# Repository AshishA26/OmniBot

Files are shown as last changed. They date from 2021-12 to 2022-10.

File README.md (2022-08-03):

# OmniBot
A remote-controlled robot that has the ability to move in more directions than usually possible using unique mecanum wheels. 
Controlled using a custom-designed Joystick and nRF24L01 module.
Programmed in `Platform IO`, models created in `Solidworks`, schematics created in `KiCad`.

Some very short demos below (click on each one to visit the full video):
Link to youtube video (https://www.youtube.com/watch?v=i19Mjydu3dY)
Link to youtube video (https://www.youtube.com/watch?v=ooEIl0JvQ7g)

## Notes
- Upload the OmniBot-Joystick.ino in the `src/OmniBot-Joystick` folder to the joystick
- The entire `Platform IO` project is to be uploaded to the OmniBot
- The OmniBot-Joystick is a slightly modified version of my [RC-Joystick](https://github.com/AshishA26/RC-Joystick).

## Schematics
Schematic for the OmniBot:
OmniBot Schematic

Schematic for the OmniBot Joystick:
OmniBot Joystick Schematic

## Images

The OmniBot and Joystick side by side:
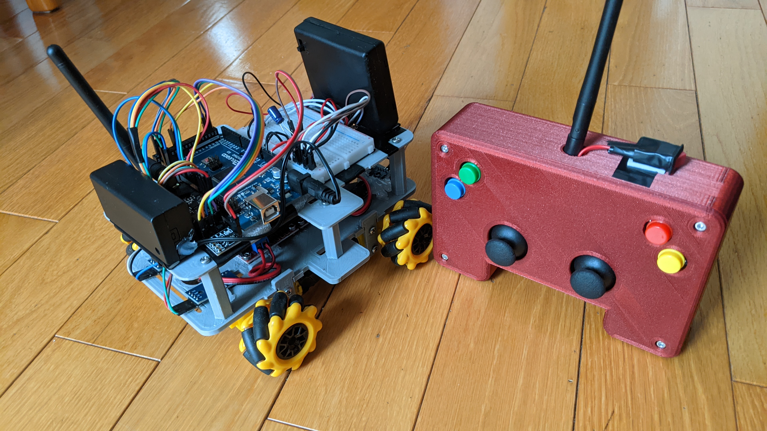
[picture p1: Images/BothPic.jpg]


<!--The OmniBot:
<img src="./Images/OmniBotPic1.jpg" width="" height="200">
<img src="./Images/OmniBotPic2.jpg" width="" height="200">
-->

Inside the joystick:
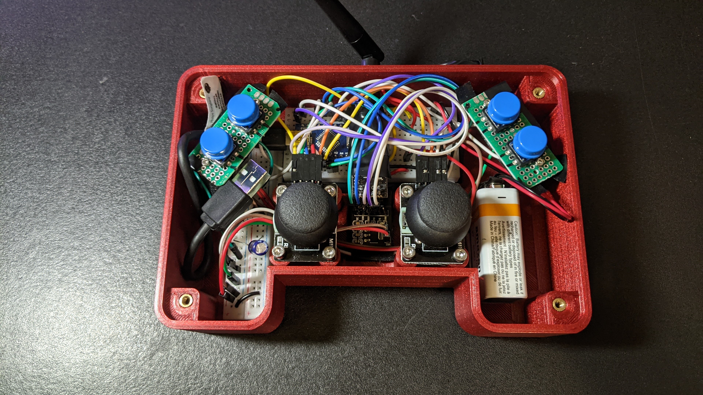
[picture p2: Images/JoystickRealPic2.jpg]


Rendered pictures of the 3D model I created using parts from [GrabCAD](https://grabcad.com/library) combined with my own models designed for 3D printing. Made in real-world scale and was designed using `Solidworks`:

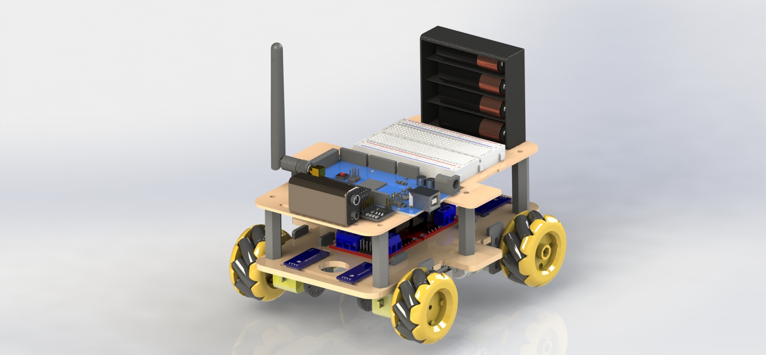
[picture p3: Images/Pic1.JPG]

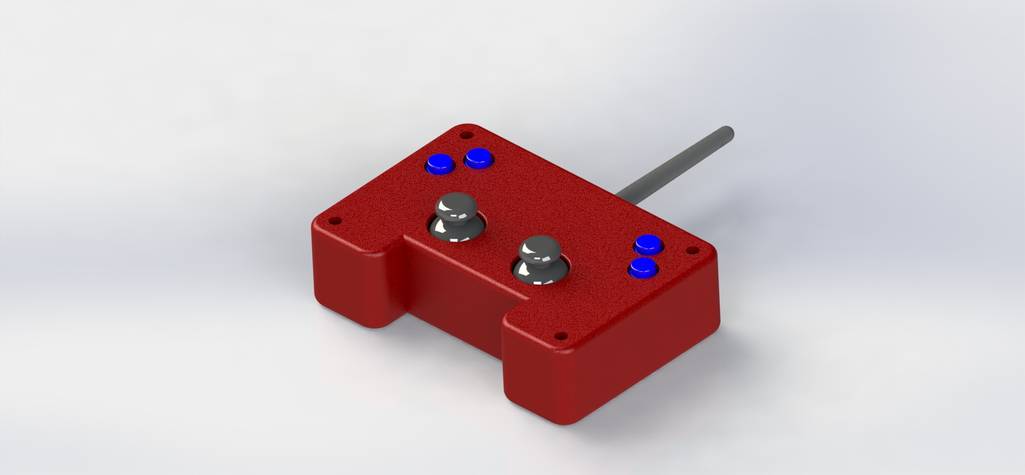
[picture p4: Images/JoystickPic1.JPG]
JoystickPic1


For more images, please see the [images folder](https://github.com/AshishA26/OmniBot/tree/master/Images) of this repo.

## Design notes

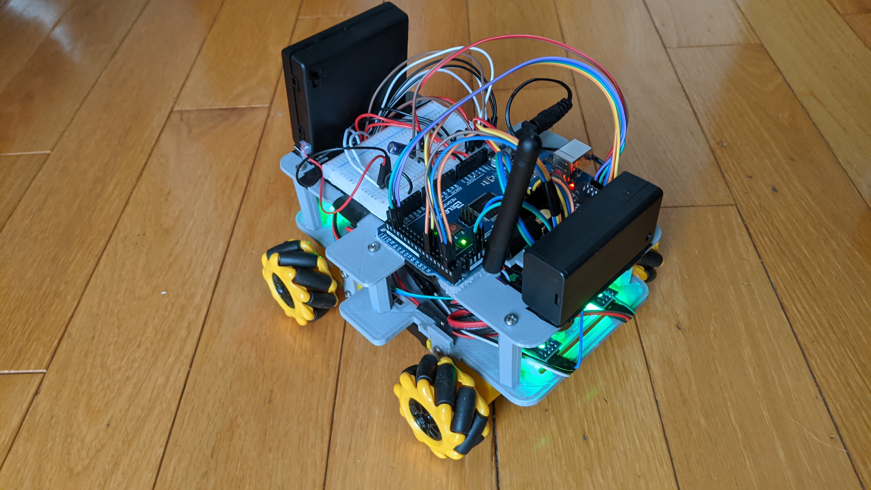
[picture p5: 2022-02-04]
Images/OmniBotPic1.jpg

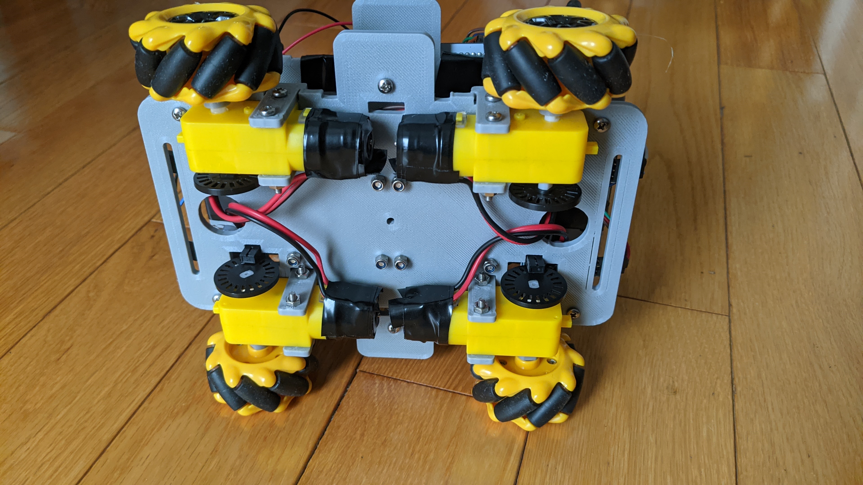
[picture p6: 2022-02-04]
Images/OmniBotPic2.jpg

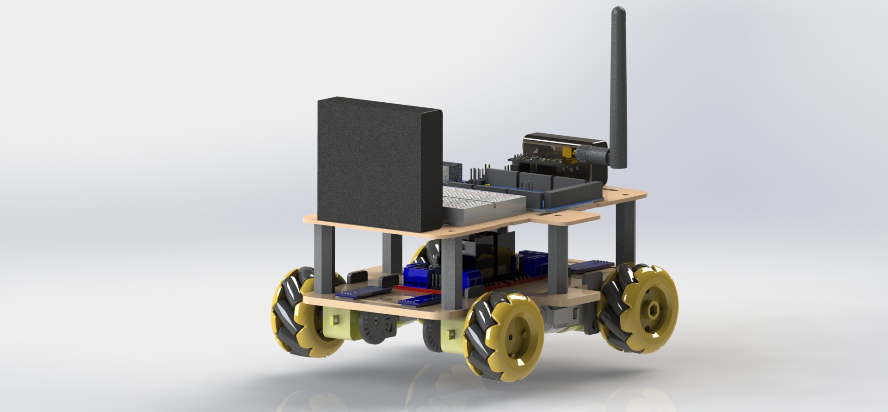
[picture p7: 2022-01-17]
Images/Pic2.JPG

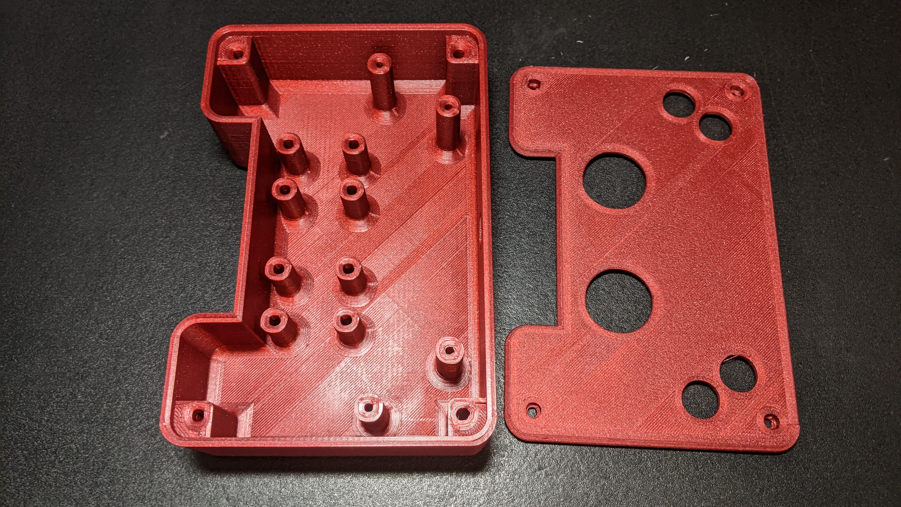
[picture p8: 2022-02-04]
Images/JoystickRealPic3.jpg

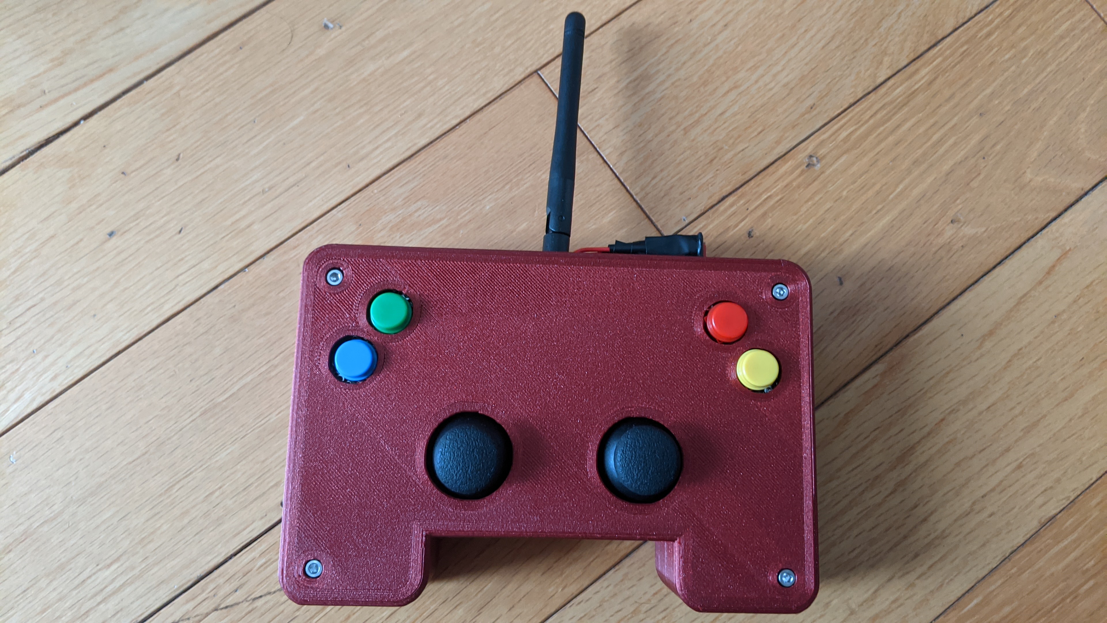
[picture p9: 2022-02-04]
Images/JoystickRealPic1.jpg

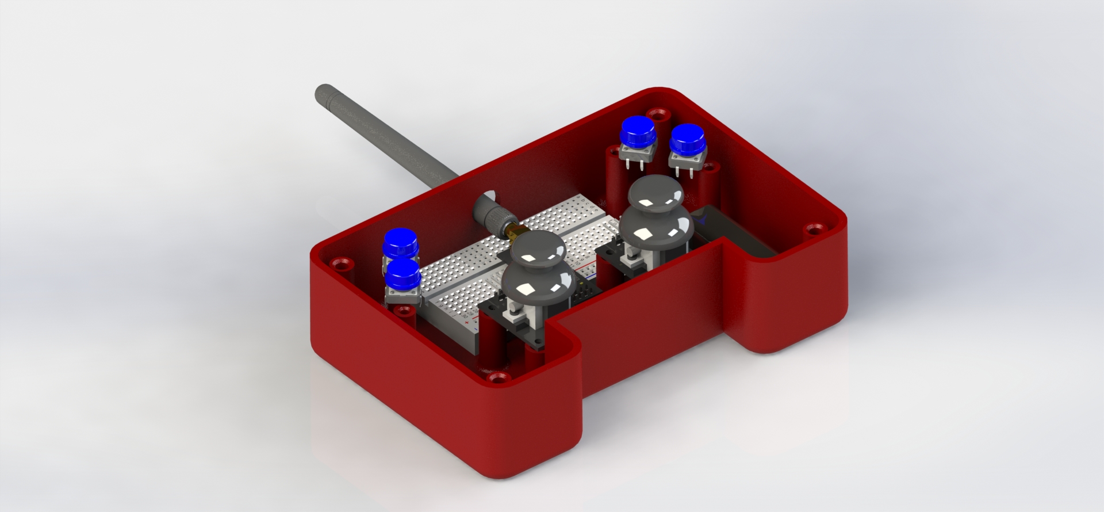
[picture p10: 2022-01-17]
Images/JoystickPic2.JPG

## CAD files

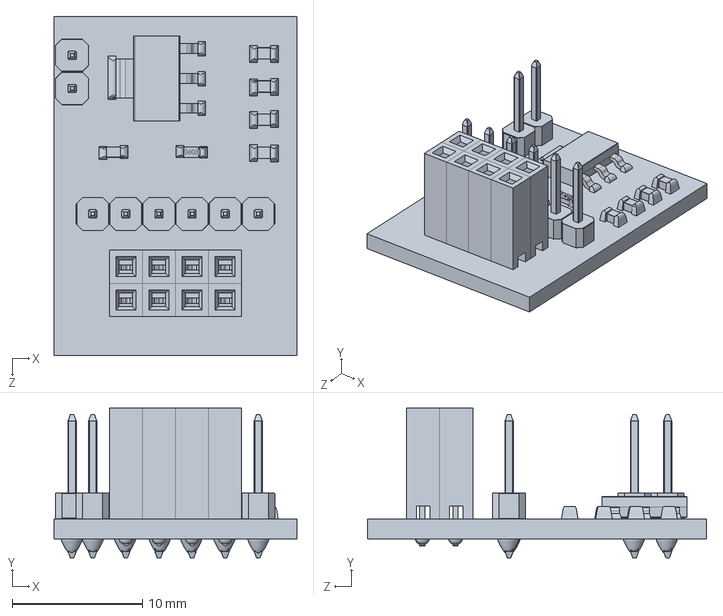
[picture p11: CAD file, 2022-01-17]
Models/OmniBotAssembly/NRFL24L01_Power_Board_asm.SLDPRT
18.6 x 11.5 x 26.0 mm

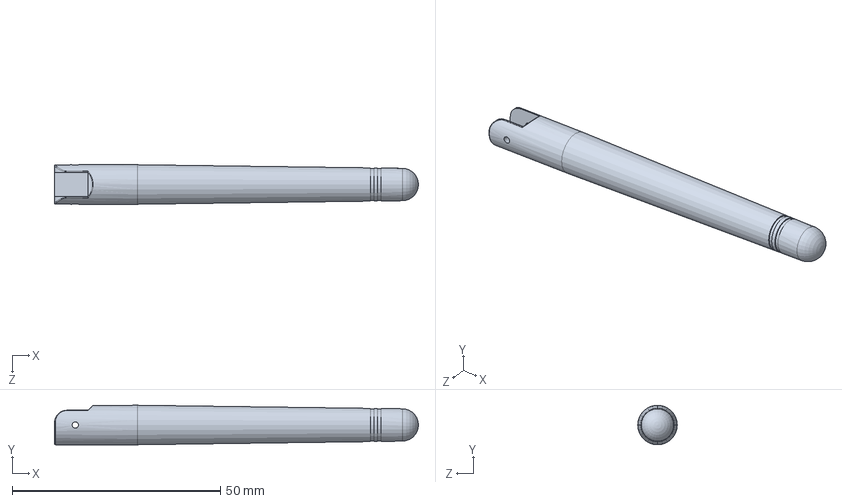
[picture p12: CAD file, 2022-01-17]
Models/OmniBotAssembly/Antenna.SLDPRT
87.5 x 9.50 x 9.50 mm

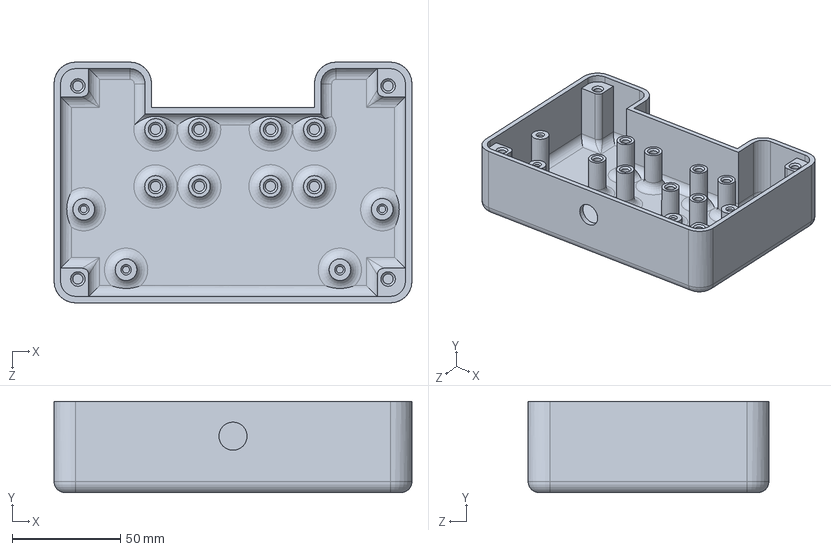
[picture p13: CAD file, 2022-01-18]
Models/OmniBotJoystickAssembly/Joystick.SLDPRT
165.0 x 42.0 x 111.0 mm

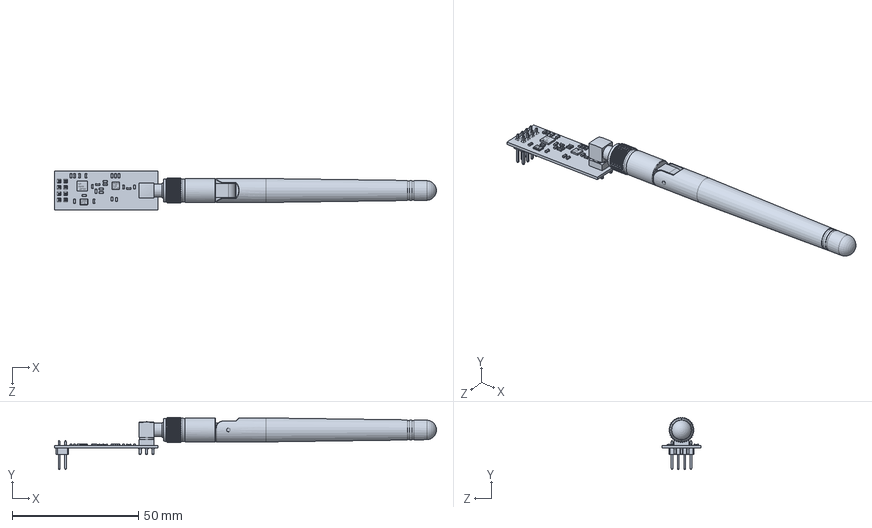
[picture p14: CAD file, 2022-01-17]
Models/OmniBotAssembly/NRF24L01L+Antenna.SLDPRT
151.4 x 20.7 x 15.5 mm

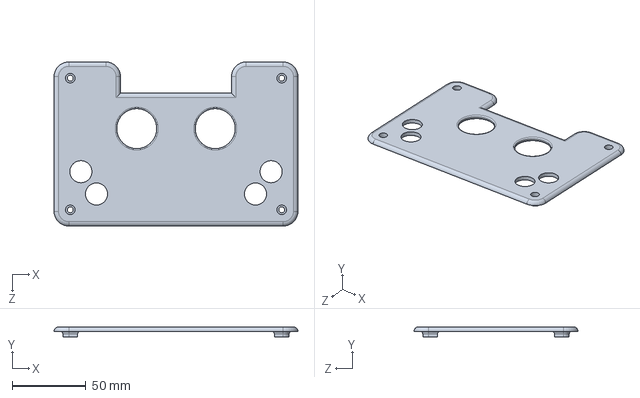
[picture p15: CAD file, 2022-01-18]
Models/OmniBotJoystickAssembly/Joystick_Lid.SLDPRT
165.0 x 6.90 x 111.0 mm

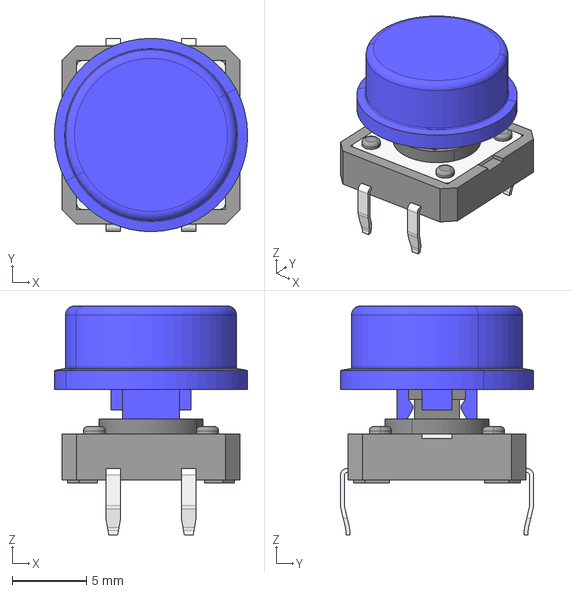
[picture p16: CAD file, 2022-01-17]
Models/OmniBotJoystickAssembly/Button microswitch_P-B1729+B17172_blue.stp
13.0 x 13.0 x 15.4 mm

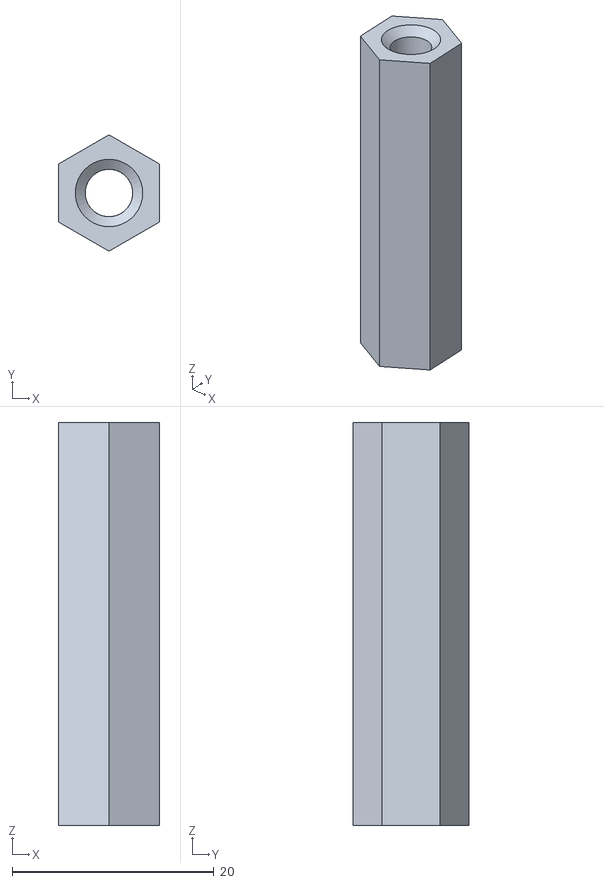
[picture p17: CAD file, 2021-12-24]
Models/STL/StandOffs.STL
10.0 x 11.5 x 40.0

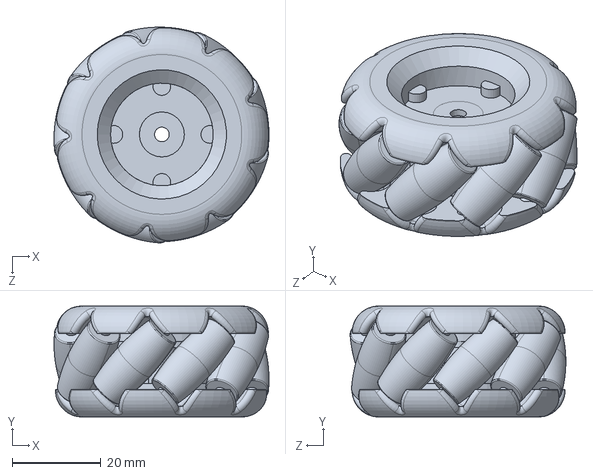
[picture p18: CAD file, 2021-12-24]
Models/OmniBotAssembly/Mecanum Left.SLDPRT
48.4 x 25.0 x 48.6 mm

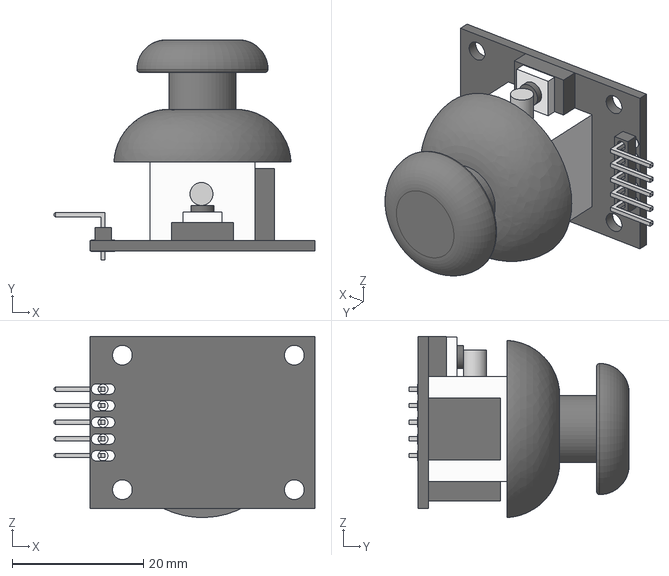
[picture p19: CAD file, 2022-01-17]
Models/OmniBotJoystickAssembly/joy_stick_2a.step
39.8 x 33.6 x 27.6 mm

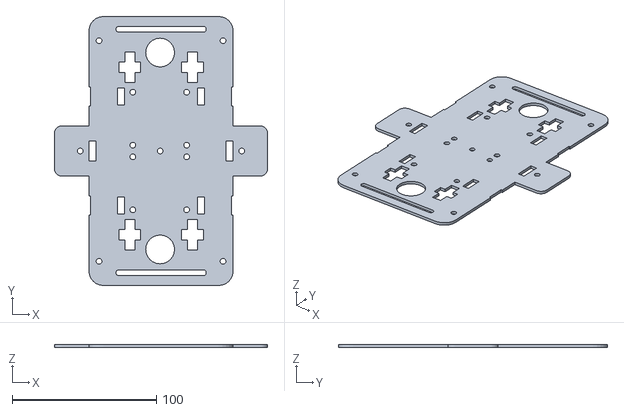
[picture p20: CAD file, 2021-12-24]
Models/STL/ChassisTop.STL
148.0 x 186.7 x 2.00

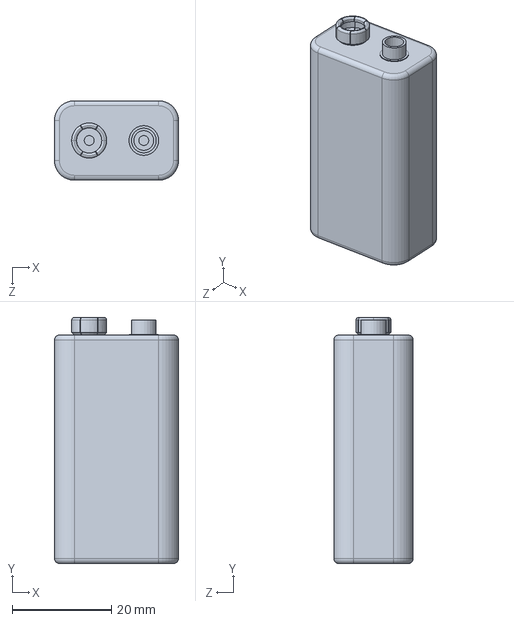
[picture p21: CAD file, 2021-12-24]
Models/OmniBotAssembly/9V-2.SLDPRT
25.0 x 49.5 x 16.0 mm

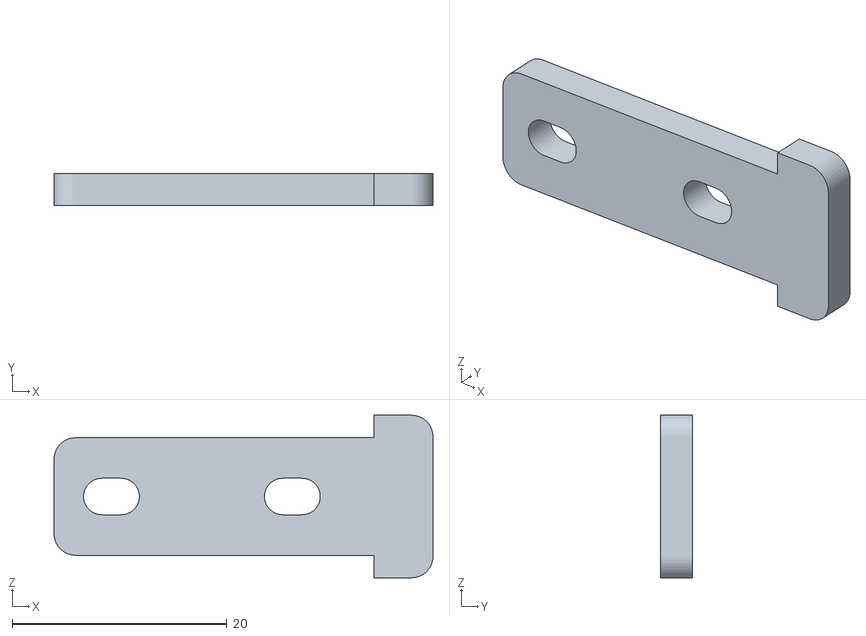
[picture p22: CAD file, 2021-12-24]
Models/STL/MotorStands.STL
35.3 x 3.00 x 15.2

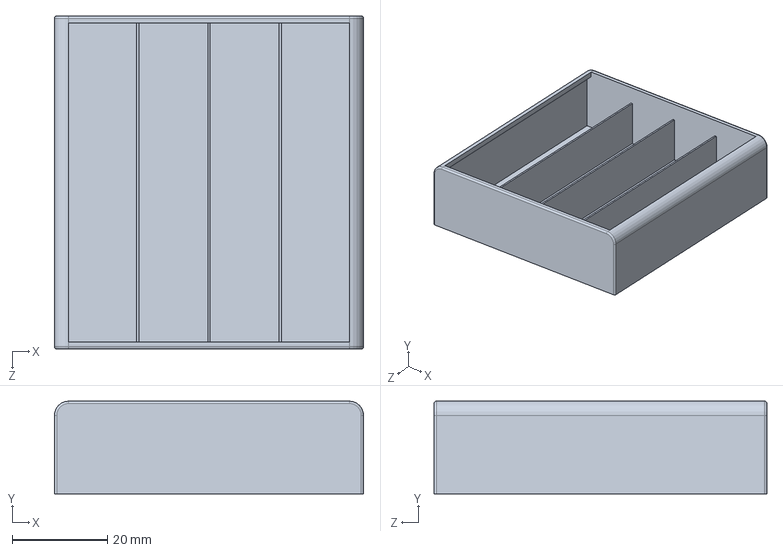
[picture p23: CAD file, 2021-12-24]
Models/OmniBotAssembly/Battery Holder.SLDPRT
65.0 x 19.5 x 70.0 mm

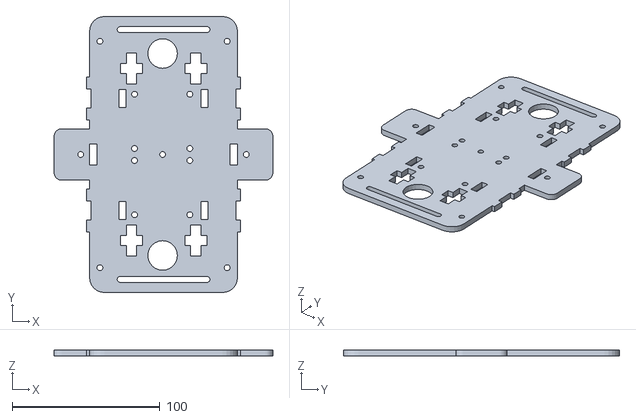
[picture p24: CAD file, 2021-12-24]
Models/STL/ChassisBottom.STL
148.0 x 186.7 x 4.00

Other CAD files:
Models/STL/Joystick.STL
Models/STL/Joystick_Lid.STL
Models/OmniBotJoystickAssembly/joy_stick_a2.iges
Models/OmniBotAssembly/AA Duracell Body.SLDPRT
Models/OmniBotAssembly/Arduino Mega 2560.SLDPRT
Models/OmniBotAssembly/ChassisBottom.SLDPRT
Models/OmniBotAssembly/ChassisTop.SLDPRT
Models/OmniBotAssembly/Lm393 Motor Speed Measuring Sensor Module.SLDPRT
Models/OmniBotAssembly/Motor Stand.SLDPRT
Models/OmniBotAssembly/Motor.SLDDRW
Models/OmniBotAssembly/Motor.SLDPRT
Models/OmniBotAssembly/StandOffs.SLDPRT
Models/OmniBotAssembly/encoder20p.SLDPRT

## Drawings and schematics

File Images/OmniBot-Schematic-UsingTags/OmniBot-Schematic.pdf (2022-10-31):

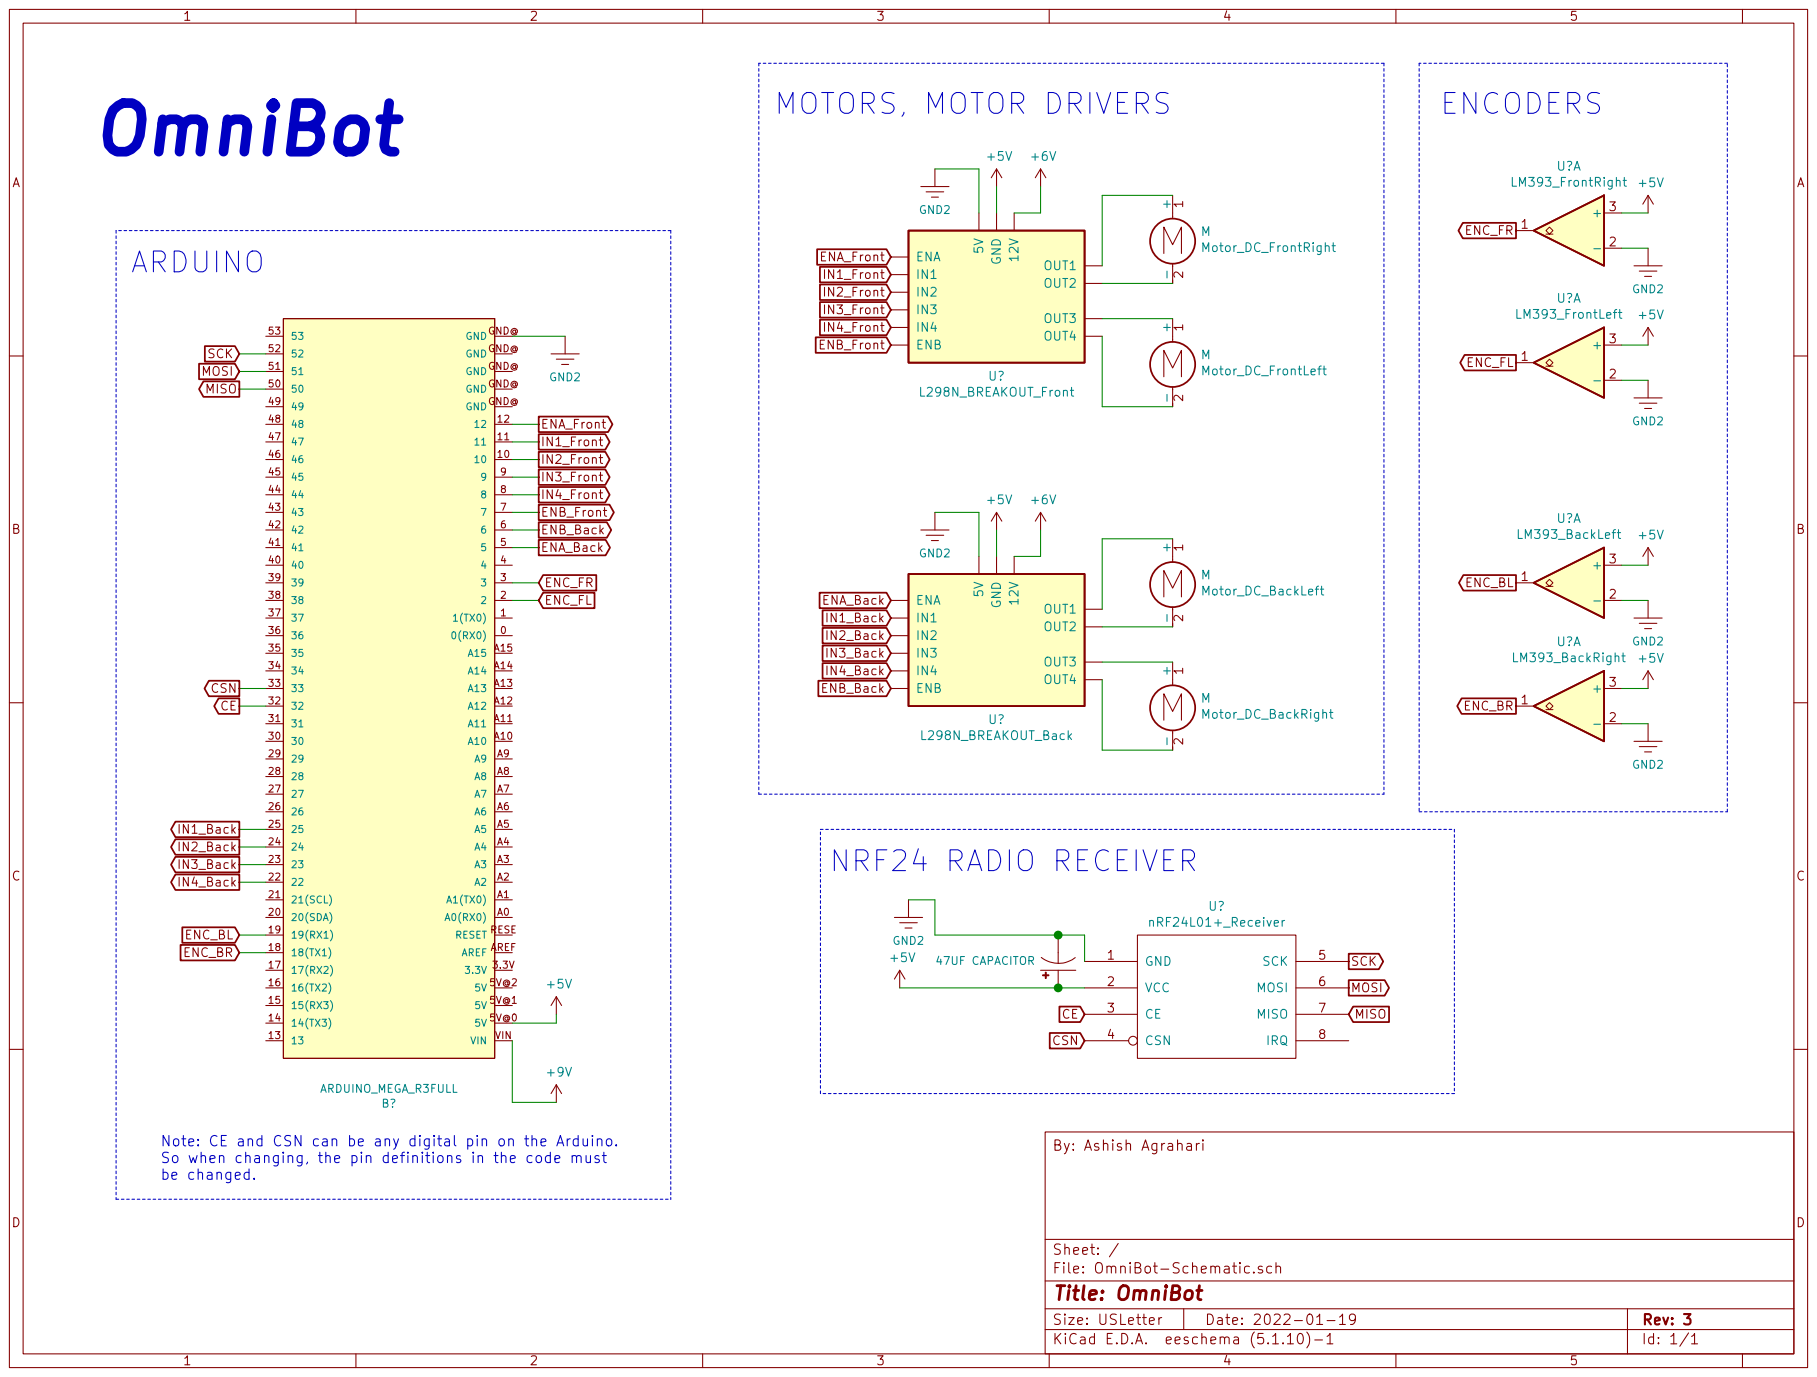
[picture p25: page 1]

Id: 1/1 Title: OmniBot File: OmniBot-Schematic.sch Sheet: / By: Ashish Agrahari 47UF CAPACITOR

Note: CE and CSN can be any digital pin on the Arduino.
So when changing, the pin definitions in the code must
be changed.

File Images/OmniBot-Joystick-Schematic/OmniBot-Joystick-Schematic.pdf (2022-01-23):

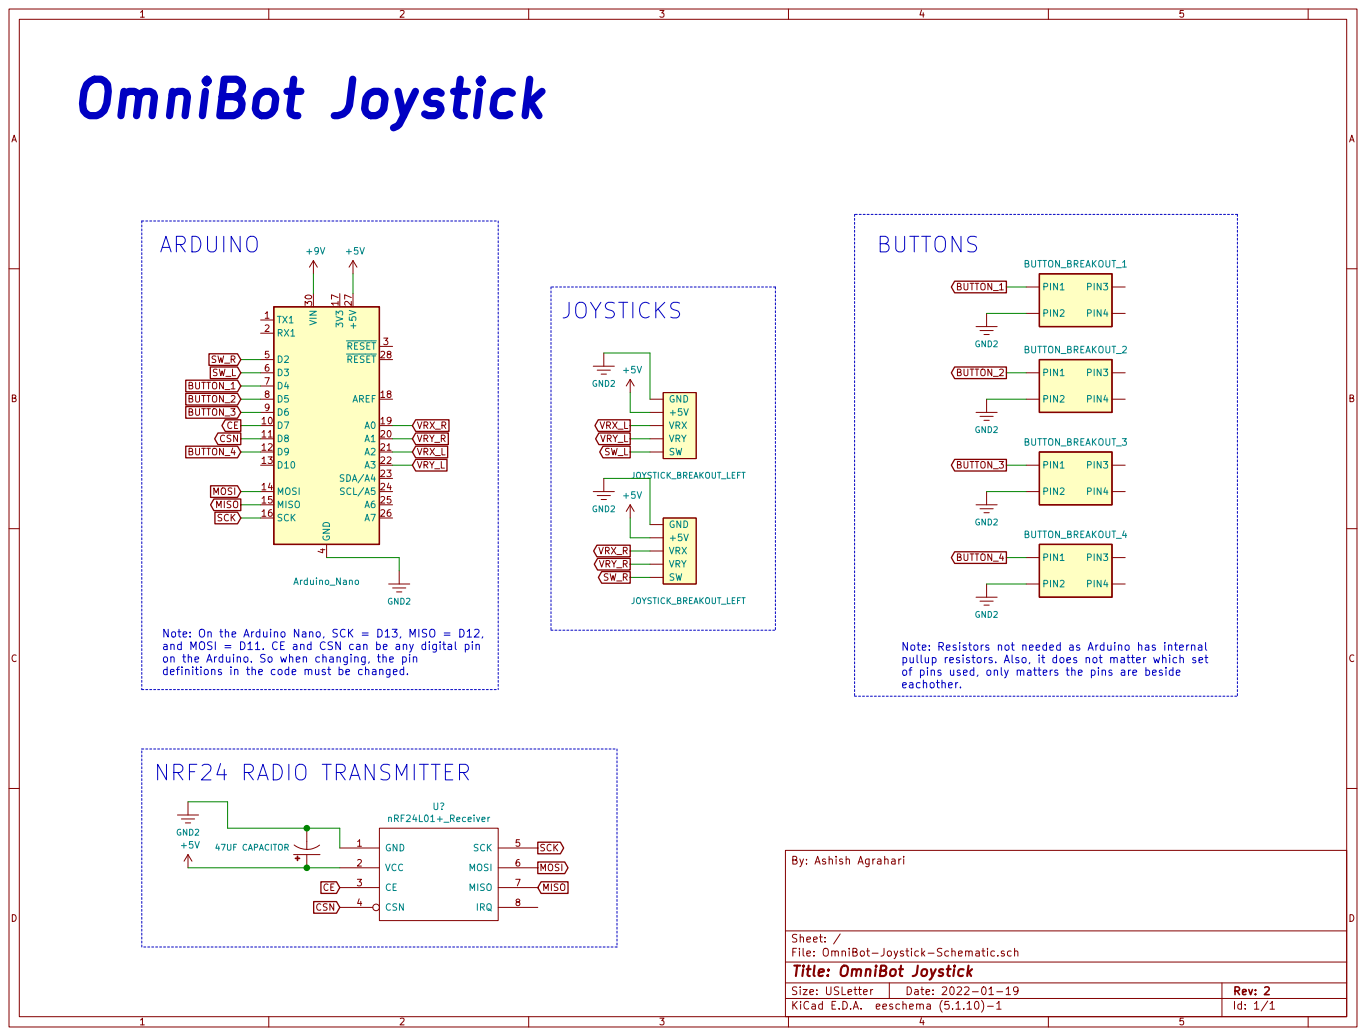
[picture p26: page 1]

of pins used, only matters the pins are beside eachother. ARDUINO

File: OmniBot-Joystick-Schematic.sch Sheet: / By: Ashish Agrahari +5V GND

Note: On the Arduino Nano, SCK = D13, MISO = D12,
and MOSI = D11. CE and CSN can be any digital pin
on the Arduino. So when changing, the pin
definitions in the code must be changed.

Id: 1/1 Title: OmniBot Joystick

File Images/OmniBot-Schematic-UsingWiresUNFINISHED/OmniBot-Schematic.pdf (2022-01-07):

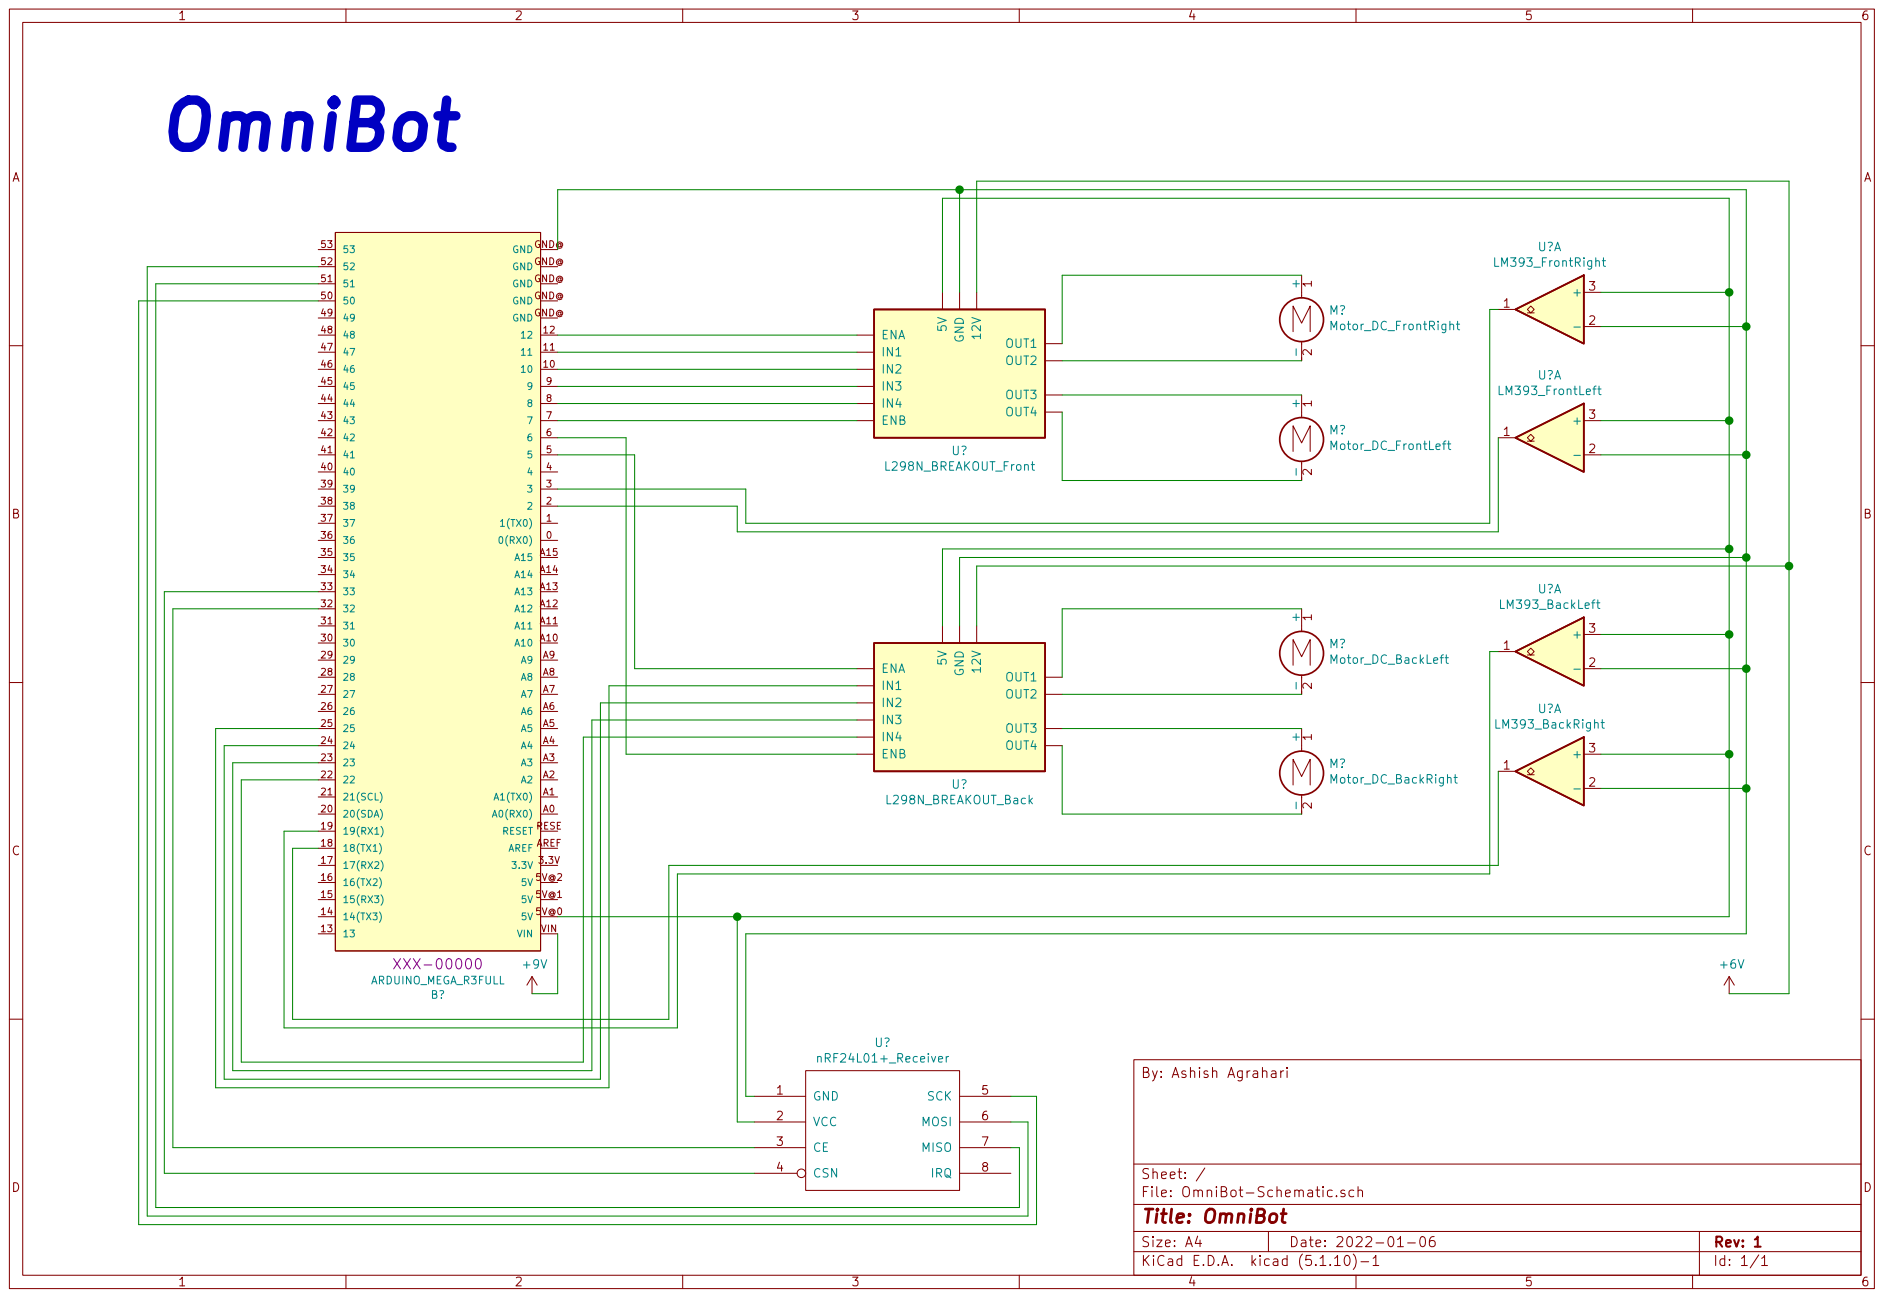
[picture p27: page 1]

51 51 GNDGND@
50 50 GNDGND@

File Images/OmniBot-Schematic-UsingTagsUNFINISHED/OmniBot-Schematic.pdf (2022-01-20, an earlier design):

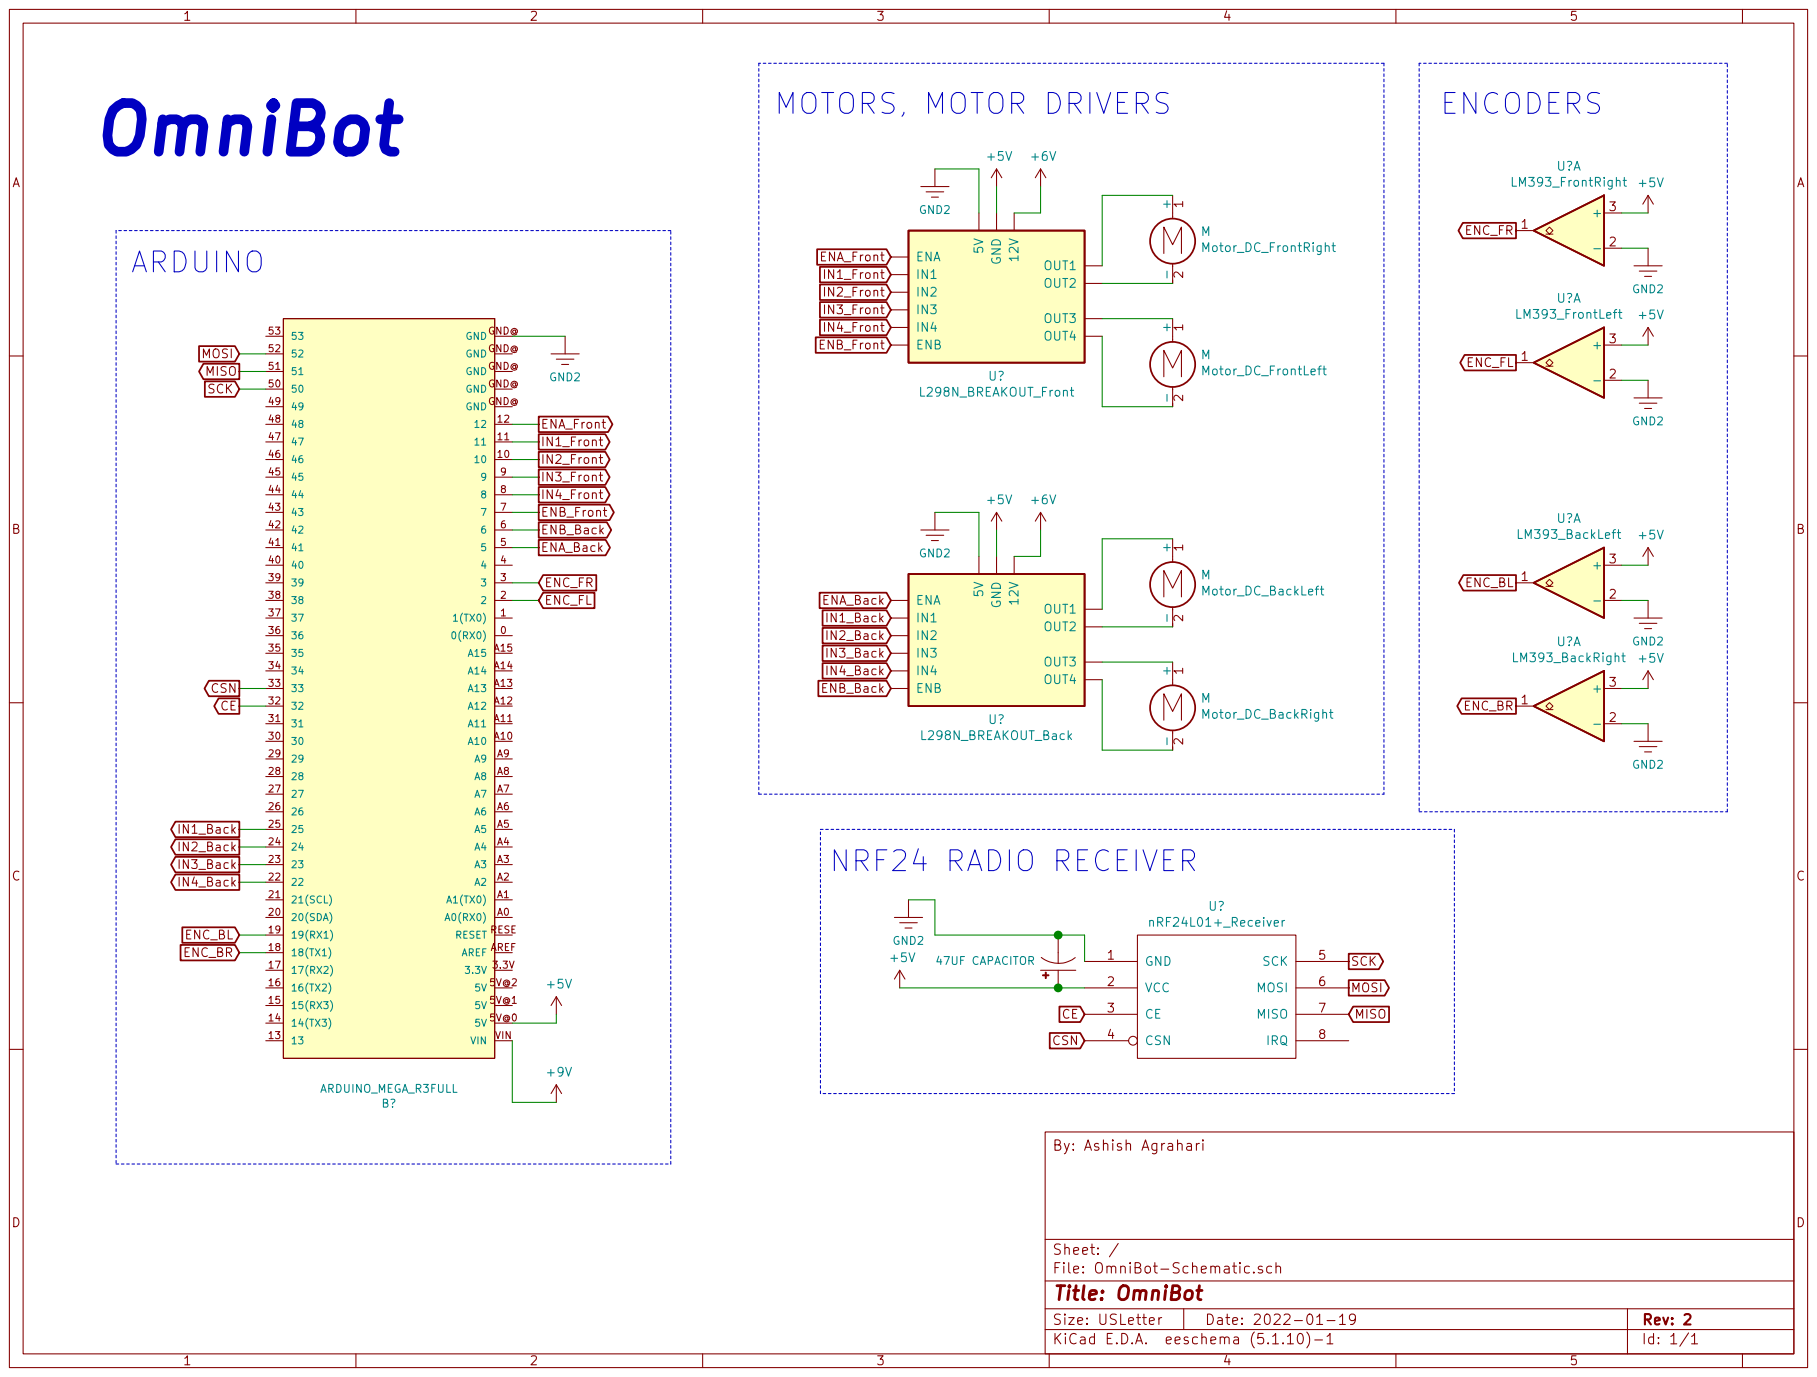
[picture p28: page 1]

Id: 1/1 Title: OmniBot File: OmniBot-Schematic.sch Sheet: / By: Ashish Agrahari

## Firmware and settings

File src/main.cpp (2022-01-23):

// Use with 4 yellow motors.

#include <Arduino.h>
#include <SPI.h>
#include <nRF24L01.h>
#include <RF24.h>

RF24 radio(32, 33); // nRF24L01 (CE, CSN), can be any digital pin on the arduino
const byte address[6] = "00001";
unsigned long lastReceiveTime = 0;
unsigned long currentTime = 0;
// Max size of this struct is 32 bytes - NRF24L01 buffer limit
struct Data_Package
{
  byte j1PotX;
  byte j1PotY;
  byte j1Button;
  byte j2PotX;
  byte j2PotY;
  byte j2Button;
  byte button1;
  byte button2;
  byte button3;
  byte button4;
};
Data_Package data; //Create a variable with the above structure

// Constants for Interrupt Pins
const byte MOTOR_A = 3;  // Motor 1 Interrupt Pin - INT 1 - Front Right Motor
const byte MOTOR_B = 2;  // Motor 2 Interrupt Pin - INT 0 - Front Left Motor
const byte MOTOR_C = 18; // Motor 3 Interrupt Pin - INT 2 - Back Left Motor
const byte MOTOR_D = 19; // Motor 4 Interrupt Pin - INT 3 - Back Right Motor

// Constant for steps in disk
const float stepcount = 20.00; // 20 Slots in disk, change if different

// Constant for wheel diameter
const float wheeldiameter = 48; // Wheel diameter in millimeters, change if different

// Integers for pulse counters
volatile int counter_A = 0;
volatile int counter_B = 0;
volatile int counter_C = 0;
volatile int counter_D = 0;

// Motor A (front right)
int enA = 5;
int in1 = 25;
int in2 = 24;

// Motor B (front left)
int enB = 6;
int in3 = 23;
int in4 = 22;

// Motor C (back left)
int enC = 12;
int in5 = 11;
int in6 = 10;

// Motor D (back right)
int enD = 7;
int in7 = 9;
int in8 = 8;

// Interrupt Service Routines

// Motor A pulse count ISR
void ISR_countA()
{
  counter_A++; // increment Motor A counter value
}

// Motor B pulse count ISR
void ISR_countB()
{
  counter_B++; // increment Motor B counter value
}
// Motor B pulse count ISR
void ISR_countC()
{
  counter_C++; // increment Motor C counter value
}
// Motor B pulse count ISR
void ISR_countD()
{
  counter_D++; // increment Motor D counter value
}

// Function to convert from centimeters to steps
int CMtoSteps(float cm)
{
  int result;                                        // Final calculation result
  float circumference = (wheeldiameter * 3.14) / 10; // Calculate wheel circumference in cm
  float cm_step = circumference / stepcount;         // CM per Step
  float f_result = cm / cm_step;                     // Calculate result as a float
  result = (int)f_result;                            // Convert to an integer (note this is NOT rounded)

  return result; // End and return result
}

/* 
SetMotorDirection()
  Sets the pins on a motor to either HIGH or LOW based on the inputs.
  Input Types: int
  Inputs: pinNumber1, pinNumber2, pinLevel1, pinLevel2
*/
void SetMotorDirection(int pinNumber1, int pinNumber2, int pinLevel1, int pinLevel2)
{
  if (pinLevel1 == 1)
  {
    digitalWrite(pinNumber1, HIGH);
  }
  else
  {
    digitalWrite(pinNumber1, LOW);
  }
  if (pinLevel2 == 1)
  {
    digitalWrite(pinNumber2, HIGH);
  }
  else
  {
    digitalWrite(pinNumber2, LOW);
  }
}

/* 
ResetCounters()
  Resets all step counters to 0.
  Input Types: None
  Inputs: None
*/
void ResetCounters()
{
  counter_A = 0; //  reset counter A to zero
  counter_B = 0; //  reset counter B to zero
  counter_C = 0; //  reset counter B to zero
  counter_D = 0; //  reset counter B to zero
}

/* 
RunMotors()
  Runs the motors at specified speed and for a specified length.
  Input Types: int
  Inputs: steps, speed
*/
void RunMotors(int step, int speed)
{
  while (step > counter_A && step > counter_B && step > counter_C && step > counter_D)
  {
    if (step > counter_A)
    {
      analogWrite(enA, speed);
    }
    else
    {
      analogWrite(enA, 0);
    }
    if (step > counter_B)
    {
      analogWrite(enB, speed);
    }
    else
    {
      analogWrite(enB, 0);
    }
    if (step > counter_C)
    {
      analogWrite(enC, speed);
    }
    else
    {
      analogWrite(enC, 0);
    }
    if (step > counter_D)
    {
      analogWrite(enD, speed);
    }
    else
    {
      analogWrite(enD, 0);
    }
  }
  // Stop when done
  analogWrite(enA, 0);
  analogWrite(enB, 0);
  analogWrite(enC, 0);
  analogWrite(enD, 0);

  ResetCounters(); // Reset all counters
}

// Function to Move Forward
void MoveForward(int steps, int mspeed)
{
  ResetCounters(); // Reset all counters

  SetMotorDirection(in1, in2, 1, 0); // Set Motor A forward
  SetMotorDirection(in3, in4, 1, 0); // Set Motor B forward
  SetMotorDirection(in5, in6, 0, 1); // Set Motor C forward
  SetMotorDirection(in7, in8, 0, 1); // Set Motor D forward

  RunMotors(steps, mspeed); // Run motors for specified steps and speed
}

// Function to Move in Reverse
void MoveReverse(int steps, int mspeed)
{
  ResetCounters(); // Reset all counters

  SetMotorDirection(in1, in2, 0, 1); // Set Motor A reverse
  SetMotorDirection(in3, in4, 0, 1); // Set Motor B reverse
  SetMotorDirection(in5, in6, 1, 0); // Set Motor C reverse
  SetMotorDirection(in7, in8, 1, 0); // Set Motor D reverse

  RunMotors(steps, mspeed); // Run motors for specified steps and speed
}

// Function to Move Right Sideways
void MoveRight(int steps, int mspeed)
{
  ResetCounters(); // Reset all counters

  SetMotorDirection(in1, in2, 0, 1); // Set Motor A reverse
  SetMotorDirection(in3, in4, 1, 0); // Set Motor B forward
  SetMotorDirection(in5, in6, 1, 0); // Set Motor C reverse
  SetMotorDirection(in7, in8, 0, 1); // Set Motor D forward

  RunMotors(steps, mspeed); // Run motors for specified steps and speed
}

// Function to Move Left Sideways
void MoveLeft(int steps, int mspeed)
{
  ResetCounters(); // Reset all counters

  SetMotorDirection(in1, in2, 1, 0); // Set Motor A forward
  SetMotorDirection(in3, in4, 0, 1); // Set Motor B reverse
  SetMotorDirection(in5, in6, 0, 1); // Set Motor C forward
  SetMotorDirection(in7, in8, 1, 0); // Set Motor D reverse

  RunMotors(steps, mspeed); // Run motors for specified steps and speed
}

// Function to Move Right Forward
void MoveRightForward(int steps, int mspeed)
{
  ResetCounters(); // Reset all counters

  SetMotorDirection(in1, in2, 0, 0); // Set Motor A stopped
  SetMotorDirection(in3, in4, 1, 0); // Set Motor B forward
  SetMotorDirection(in5, in6, 0, 0); // Set Motor C stopped
  SetMotorDirection(in7, in8, 0, 1); // Set Motor D forward

  RunMotors(steps, mspeed); // Run motors for specified steps and speed
}

// Function to Move Left Forward
void MoveLeftForward(int steps, int mspeed)
{
  ResetCounters(); // Reset all counters

  SetMotorDirection(in1, in2, 1, 0); // Set Motor A forward
  SetMotorDirection(in3, in4, 0, 0); // Set Motor B stopped
  SetMotorDirection(in5, in6, 0, 1); // Set Motor C forward
  SetMotorDirection(in7, in8, 0, 0); // Set Motor D stopped

  RunMotors(steps, mspeed); // Run motors for specified steps and speed
}

// Function to Move Right reverse
void MoveRightReverse(int steps, int mspeed)
{
  ResetCounters(); // Reset all counters

  SetMotorDirection(in1, in2, 0, 1); // Set Motor A reverse
  SetMotorDirection(in3, in4, 0, 0); // Set Motor B stopped
  SetMotorDirection(in5, in6, 1, 0); // Set Motor C reverse
  SetMotorDirection(in7, in8, 0, 0); // Set Motor D stopped

  RunMotors(steps, mspeed); // Run motors for specified steps and speed
}

// Function to Move Left reverse
void MoveLeftReverse(int steps, int mspeed)
{
  ResetCounters(); // Reset all counters

  SetMotorDirection(in1, in2, 0, 0); // Set Motor A stopped
  SetMotorDirection(in3, in4, 0, 1); // Set Motor B reverse
  SetMotorDirection(in5, in6, 0, 0); // Set Motor C stopped
  SetMotorDirection(in7, in8, 1, 0); // Set Motor D forward

  RunMotors(steps, mspeed); // Run motors for specified steps and speed
}

// Function to Move Right reverse
void SpinRight(int steps, int mspeed)
{
  ResetCounters(); // Reset all counters

  SetMotorDirection(in1, in2, 0, 1); // Set Motor A reverse
  SetMotorDirection(in3, in4, 1, 0); // Set Motor B stopped
  SetMotorDirection(in5, in6, 0, 1); // Set Motor C reverse
  SetMotorDirection(in7, in8, 1, 0); // Set Motor D stopped

  RunMotors(steps, mspeed); // Run motors for specified steps and speed
}

// Function to Move Left reverse
void SpinLeft(int steps, int mspeed)
{
  ResetCounters(); // Reset all counters

  SetMotorDirection(in1, in2, 1, 0); // Set Motor A stopped
  SetMotorDirection(in3, in4, 0, 1); // Set Motor B reverse
  SetMotorDirection(in5, in6, 1, 0); // Set Motor C stopped
  SetMotorDirection(in7, in8, 0, 1); // Set Motor D forward

  RunMotors(steps, mspeed); // Run motors for specified steps and speed
}

// Function to Move Left reverse
void Stop()
{
  ResetCounters(); // Reset all counters

  SetMotorDirection(in1, in2, 0, 0); // Set Motor A stopped
  SetMotorDirection(in3, in4, 0, 0); // Set Motor B reverse
  SetMotorDirection(in5, in6, 0, 0); // Set Motor C stopped
  SetMotorDirection(in7, in8, 0, 0); // Set Motor D forward

  RunMotors(0, 0); // Run motors for specified steps and speed
}

void attachInterrupts()
{
  // Attach the Interrupts to their ISR's
  attachInterrupt(digitalPinToInterrupt(MOTOR_A), ISR_countA, RISING); // Increase counter A when speed sensor pin goes High
  attachInterrupt(digitalPinToInterrupt(MOTOR_B), ISR_countB, RISING); // Increase counter B when speed sensor pin goes High
  attachInterrupt(digitalPinToInterrupt(MOTOR_C), ISR_countC, RISING); // Increase counter C when speed sensor pin goes High
  attachInterrupt(digitalPinToInterrupt(MOTOR_D), ISR_countD, RISING); // Increase counter D when speed sensor pin goes High
}

void resetData()
{
  // Reset the values when there is no radio connection - Set initial default values
  data.j1PotX = 127;
  data.j1PotY = 127;
  data.j2PotX = 127;
  data.j2PotY = 127;
  data.j1Button = 1;
  data.j2Button = 1;
  data.button1 = 1;
  data.button2 = 1;
  data.button3 = 1;
  data.button4 = 1;
}

void setup()
{

  Serial.begin(9600);
  radio.begin();
  radio.openReadingPipe(0, address);
  radio.setAutoAck(false);
  radio.setDataRate(RF24_250KBPS);
  radio.setPALevel(RF24_PA_MIN); // It was originally LOW
  radio.startListening();        //  Set the module as receiver
  resetData();

  attachInterrupts(); // Attach the Interrupts to their ISR's

  // Test Motor Movement:
  // MoveForward(CMtoSteps(20), 255); // Ex: Forward at 255 speed for 20cm
  // delay(1000);                     // Wait one second
  // MoveReverse(CMtoSteps(20), 255);
  // delay(1000);
  // MoveRight(CMtoSteps(20), 255);
  // delay(1000);
  // MoveLeft(CMtoSteps(20), 255);
  // delay(1000);
  // MoveLeftForward(CMtoSteps(20), 255);
  // delay(1000);
  // MoveRightForward(CMtoSteps(20), 255);
  // delay(1000);
  // MoveLeftReverse(CMtoSteps(20), 255);
  // delay(1000);
  // MoveRightReverse(CMtoSteps(20), 255);
  // delay(1000);
  // SpinLeft(CMtoSteps(20), 255);
  // delay(1000);
  // SpinRight(CMtoSteps(20), 255);
  // delay(1000);
}

void loop()
{
  // Check whether there is data to be received
  if (radio.available())
  {
    radio.read(&data, sizeof(Data_Package)); // Read the whole data and store it into the 'data' structure
    lastReceiveTime = millis();              // At this moment we have received the data
  }
  // Check whether we keep receving data, or we have a connection between the two modules
  currentTime = millis();
  if (currentTime - lastReceiveTime > 1000)
  {              // If current time is more then 1 second since we have recived the last data, that means we have lost connection
    resetData(); // If connection is lost, reset the data. It prevents unwanted behavior, for example if a drone has a throttle up and we lose connection, it can keep flying unless we reset the values
  }

  if (data.j1PotY > 150)
  {
    MoveLeft(CMtoSteps(1), 255);
  }
  else if (data.j1PotY < 100)
  {
    MoveRight(CMtoSteps(1), 255);
  }
  else if (data.j1PotX > 160)
  {
    MoveReverse(CMtoSteps(1), 255);
  }
  else if (data.j1PotX < 100)
  {
    MoveForward(CMtoSteps(1), 255);
  }
  else if (data.j2PotY < 100 && data.j2PotX > 160)
  {
    MoveLeftForward(CMtoSteps(1), 255);
  }
  else if (data.j2PotY > 160 && data.j2PotX > 160)
  {
    MoveLeftReverse(CMtoSteps(1), 255);
  }
  else if (data.j2PotY < 100 && data.j2PotX < 100)
  {
    MoveRightForward(CMtoSteps(1), 255);
  }
  else if (data.j2PotY > 160 && data.j2PotX < 100)
  {
    MoveRightReverse(CMtoSteps(1), 255);
  }
  else if (data.j2PotX < 100)
  {
    SpinRight(CMtoSteps(1), 255);
  }
  else if (data.j2PotX > 150)
  {
    SpinLeft(CMtoSteps(1), 255);
  }
  else
  {
    Stop();
  }

  // Print the data in the Serial Monitor

  // Use this portion below to see in the SERIAL PLOTTER

  // Serial.print(data.j1PotX);
  // Serial.print(" ");
  // Serial.print(data.j1PotY);
  // Serial.print(" ");
  // Serial.print(data.j2PotX);
  // Serial.print(" ");
  // Serial.print(data.j2PotY);
  // Serial.print(" ");
  // Serial.print(data.button1);
  // Serial.print(" ");
  // Serial.print(data.button2);
  // Serial.print(" ");
  // Serial.print(data.button3);
  // Serial.print(" ");
  // Serial.print(data.button4);
  // Serial.println("");

  // Use this portion below to see in SERIAL MONITOR

  //  Serial.print("j1PotX: ");
  //  Serial.print(data.j1PotX);
  //  Serial.print("; j1PotY: ");
  //  Serial.print(data.j1PotY);
  //  Serial.print("; j2PotX: ");
  //  Serial.println(data.j2PotX);
  //  Serial.print("; j2PotY: ");
  //  Serial.println(data.j2PotY);
  //  Serial.print("; button1: ");
  //  Serial.print(data.button1);
  //  Serial.print("; button2: ");
  //  Serial.print(data.button2);
  //  Serial.print("; button3: ");
  //  Serial.print(data.button3);
  //  Serial.print("; button4: ");
  //  Serial.print(data.button4);
  //  Serial.println("");
}

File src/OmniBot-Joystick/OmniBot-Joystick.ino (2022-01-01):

#include <SPI.h>
#include <nRF24L01.h>
#include <RF24.h>
#include <Wire.h>
// Define the digital inputs
#define jB1 2  // Joystick button 1
#define jB2 3  // Joystick button 2
#define b1 4   // Button 1
#define b2 5   // Button 2
#define b3 6   // Button 3
#define b4 9   // Button 4
#define j1PotXPin A0 //Joystick 1 axis X
#define j1PotYPin A1 //Joystick 1 axis Y
#define j2PotXPin A2 //Joystick 2 axis X
#define j2PotYPin A3 //Joystick 2 axis Y

RF24 radio(7, 8);   // nRF24L01 (CE, CSN)
const byte address[6] = "00001"; // Address

// Max size of this struct is 32 bytes - NRF24L01 buffer limit
struct Data_Package {
  byte j1PotX;
  byte j1PotY;
  byte j1Button;
  byte j2PotX;
  byte j2PotY;
  byte j2Button;
  byte button1;
  byte button2;
  byte button3;
  byte button4;
};
Data_Package data; //Create a variable with the above structure

void setup() {
  Serial.begin(9600);

  // Define the radio communication
  radio.begin();
  radio.openWritingPipe(address);
  radio.setAutoAck(false);
  radio.setDataRate(RF24_250KBPS);
  radio.setPALevel(RF24_PA_MIN); // It was originally LOW

  // Activate the Arduino internal pull-up resistors
  pinMode(jB1, INPUT_PULLUP);
  pinMode(jB2, INPUT_PULLUP);
  pinMode(b1, INPUT_PULLUP);
  pinMode(b2, INPUT_PULLUP);
  pinMode(b3, INPUT_PULLUP);
  pinMode(b4, INPUT_PULLUP);

  // Set initial default values
  data.j1PotX = 127; // Values from 0 to 255. When Joystick is in resting position, the value is in the middle, or 127. We actually map the pot value from 0 to 1023 to 0 to 255 because that's one BYTE value
  data.j1PotY = 127;
  data.j2PotX = 127;
  data.j2PotY = 127;
  data.j1Button = 1;
  data.j2Button = 1;
  data.button1 = 1;
  data.button2 = 1;
  data.button3 = 1;
  data.button4 = 1;
}

void loop() {
  // Read all analog inputs and map them to one Byte value
  data.j1PotX = map(analogRead(j1PotXPin), 0, 1023, 0, 255); // Convert the analog read value from 0 to 1023 into a BYTE value from 0 to 255
  data.j1PotY = map(analogRead(j1PotYPin), 0, 1023, 0, 255);
  data.j2PotX = map(analogRead(j2PotXPin), 0, 1023, 0, 255);
  data.j2PotY = map(analogRead(j2PotYPin), 0, 1023, 0, 255);
  // Read all digital inputs
  data.j1Button = digitalRead(jB1);
  data.j2Button = digitalRead(jB2);
  data.button1 = digitalRead(b1);
  data.button2 = digitalRead(b2);
  data.button3 = digitalRead(b3);
  data.button4 = digitalRead(b4);
  // Send the whole data from the structure to the receiver
  radio.write(&data, sizeof(Data_Package));
}

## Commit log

2021-12-24 Added 3D files
    [9V-2.SLDPRT, AA Duracell Body.SLDPRT, Arduino Mega 2560.SLDPRT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]
2021-12-24 Initialized project
    [9V-2.SLDPRT, AA Duracell Body.SLDPRT, Arduino Mega 2560.SLDPRT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]
2022-01-07 Created Schematic Diagram
    [OmniBot-Schematic.kicad_pcb, OmniBot-Schematic.sch]
2022-01-10 Created OmniBot Joystick Schematic
    [OmniBot-Joystick-Schematic.kicad_pcb, OmniBot-Joystick-Schematic.sch, OmniBot-Schematic.kicad_pcb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]
2022-01-15 Updated schematic
    [OmniBot-Joystick-Schematic.sch]
2022-01-15 Update schematic for joystick
    [OmniBot-Joystick-Schematic.sch]
2022-01-17 Created Joystick models and assembly
    [9V-2.SLDPRT, AA Duracell Body.SLDPRT, Arduino Mega 2560.SLDPRT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]
2022-01-17 updated OmniBot model
    [Antenna.SLDPRT, NRF24L01L+Antenna.SLDPRT, NRFL24L01_Power_Board_asm.SLDPRT]
2022-01-18 Update joystick model
    [Joystick.SLDPRT, Joystick.STL, Joystick_Lid.SLDPRT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]
2022-01-20 Updated schematics
    [OmniBot-Joystick-Schematic.sch, OmniBot-Schematic.kicad_pcb, OmniBot-Schematic.sch]
2022-01-23 Cleaning up
    [OmniBot-Schematic.kicad_pcb, OmniBot-Schematic.sch]
2022-01-23 Update schematic and code
    [OmniBot-Joystick-Schematic.sch, OmniBot-Schematic.sch]
